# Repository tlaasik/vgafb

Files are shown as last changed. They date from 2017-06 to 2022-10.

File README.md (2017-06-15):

# VgaFB

Minimalistic VGA framebuffer hardware and software for microcontrollers (right now only tested on Arduino Uno and Nano).

## Features
* simple hardware (just 3x2:1 mux and 64KB SPI memory chip), but just enough to have low CPU utilization
* has integraion with high level u8g2 and u8x8 API. These provide monochrome font and graphics rendering
* supports 2 colors: black and a color selected by RGB jumper
* up to 640x480 resolution (64KB address space, 1bit per pixel)
* fast screen clear and fast vertical scrolling
* (optional) generates pixel clock by multiplying MCU clock by 2x 2.5x 3x 4x or 5x
* (optional) or generates pixel clock with own oscillator 20MHz 25MHz 30Mhz 40MHz 50MHz. MCU should use it

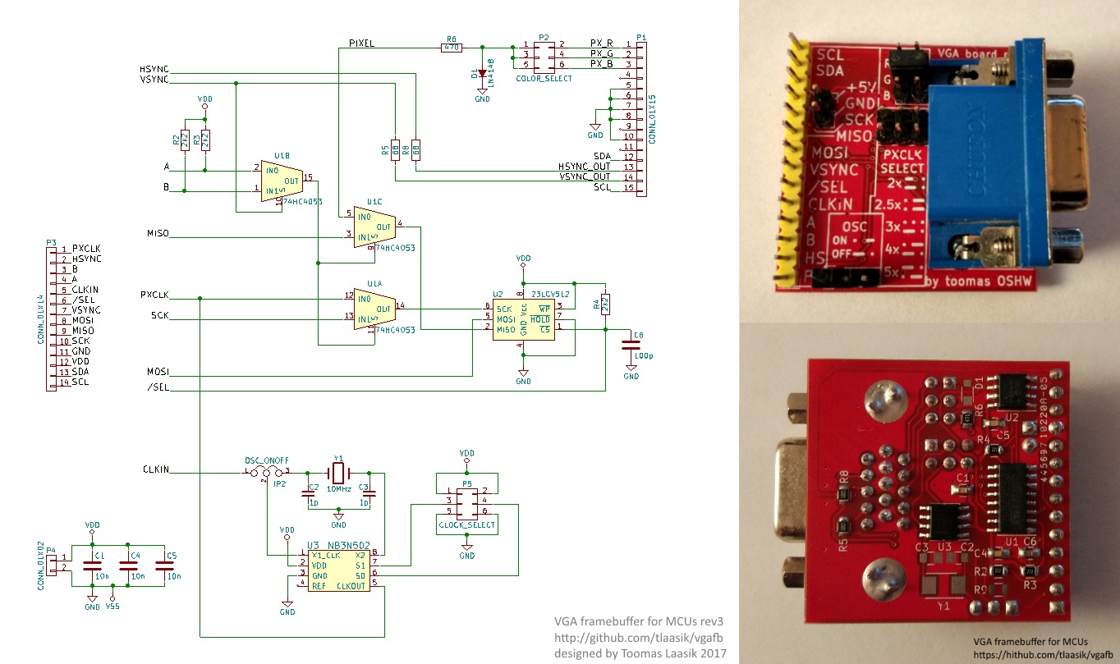
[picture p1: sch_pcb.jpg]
Schematic and pcb pictures


## Usage
1. Decide how to generate pixel clock, this may limit what resolutions are available. For example, Arduino may run at 16MHz and generate 8MHz that is fed into CLKIN. Then using 2.5x multiplier 20MHz pixel clock is generated suitable for 400x300@60Hz and 256x256@60Hz modes
2. Wire this schematic together with your Arduino board or chip
3. Download [arduino_lib/](arduino_lib/) and place the contents where your arduino libraries are (usually c:\Users\<username>3\Documents\Arduino\libraries\) or directly in your project folder
4. See [arduino_lib/examples/TextOnScreen_8x2g.ino](arduino_lib/examples/TextOnScreen_8x2g.ino)

List of modes supported (format tells screen width and height, refresh rate and required pixel clock)
* vgamode_400x300_60Hz_20MHz
* vgamode_256x256_60Hz_20MHz
* vgamode_640x480_75Hz_32MHz
* vgamode_320x240_75Hz_16MHz
* vgamode_640x400_85Hz_32MHz
* vgamode_320x200_85Hz_16MHz
* vgamode_640x480_60Hz_25MHz
* vgamode_320x240_60Hz_12_6MHz
* vgamode_160x120_60Hz_6_3MHz

Wiring to Arduino Nano
```
vgafb  ardu_nano
-------------------------------------
SCL    -       monitor I2C DDC clock, no need to connect
SDA    -       monitor I2C DDC data, no need to connect
+5V    +3..5V
GND    ground
SCK    D13     SPI clock in
MISO   D12     SPI data out
MOSI   D11     SPI data in
VSYNC  D10     vertical sync in
/SEL   D4      SPI memory chip select in
CLKIN  D3      clock in, it's multiplied to get pixel clock (right now VgaFB_Begin configures it to 8MHz)
A      D9      mode in if normal vsync, leave hi-z or drive high if inverted vsync
B      D8      mode in if inverted vsync, leave hi-z or drive high if normal vsync
HS     D5      horizontal sync in
PX     -       pixel clock out (without clock mult. chip it's pixel clock in)

/SEL, A and B pins can be assigned elsewhere on Arduino Nano. Other pins are fixed due
to hardware resources like PWM and SPI tied to specific pins.
```

## Example code
```C
#include <U8x8lib.h>
#include <SPI.h>
#include <VgaFB_u8x8.h>

U8G2_VGAFB_400X300_60Hz_20MHz_GENERIC_1_VGAFBBUS u8g2(U8G2_R0, /*mul/div=*/5, 4, /* cs=*/ 4, /* a=*/ 9);

// Generate 8MHz that will be multiplied by 2.5 (set by jumpers) to get 20MHz pixel clock.
// Since Arduino itself runs at 16MHz we told in u8g2 constructor that the multiplier is 1.25
void setupClockGen() {
	OCR2A = 0;
	TCCR2A = _BV(WGM21) | _BV(COM2B0); // toggle B on compare (pin 5, Arduino port: D3)
	TCCR2B = 1; // prescale 1
	pinMode(3, OUTPUT);
}
void setup() {
	setupClockGen();
	u8g2.begin();
}
void loop() {
	u8g2.firstPage();
	do {
		u8g2.setFont(u8g2_font_ncenB14_tr);
		u8g2.drawStr(0, 20, "VGA framebuffer for Arduino Nano");
		u8g2.drawStr(130, 260, "Running at 400x300 60Hz");
		u8g2.setFont(u8g2_font_ncenB08_tr);
		u8g2.drawStr(130, 280, "Using u8g2 for rendering text");
		u8g2.drawStr(0, 40, "https://github.com/tlaasik/vgafb");
		u8g2.drawFilledEllipse(100, 100, 90, 30);
	} while (u8g2.nextPage());
	
	_delay_ms(4000);
	VgaFB_Scroll(u8g2.getVgaFB(), 300);
	_delay_ms(800);
}
```

## Low level C API (not safe, buf fast)
```C
void VgaFB_ConfigBoard(vgafb_t * vgafb, uint8_t mul, uint8_t div, uint8_t cs_pin, uint8_t ab_pin);
bool VgaFB_Begin(vgafb_t * vgafb, vgamode_t mode);
void VgaFB_End(vgafb_t * vgafb);
void VgaFB_DisplayEnabled(vgafb_t * vgafb, bool enabled);
void VgaFB_Clear(vgafb_t * vgafb);
void VgaFB_Scroll(vgafb_t * vgafb, int16_t deltaScanline);
void VgaFB_Write(vgafb_t * vgafb, uint_vgafb_t dst, uint8_t * src, uint_vgafb_t cnt);
void VgaFB_Read(vgafb_t * vgafb, uint_vgafb_t src, uint8_t * dst, uint_vgafb_t cnt);
// uint_vgafb_t is usually uint16_t (VGAFB_VRAM_ADDR_LENGTH==2)
```

## Pictures of it working

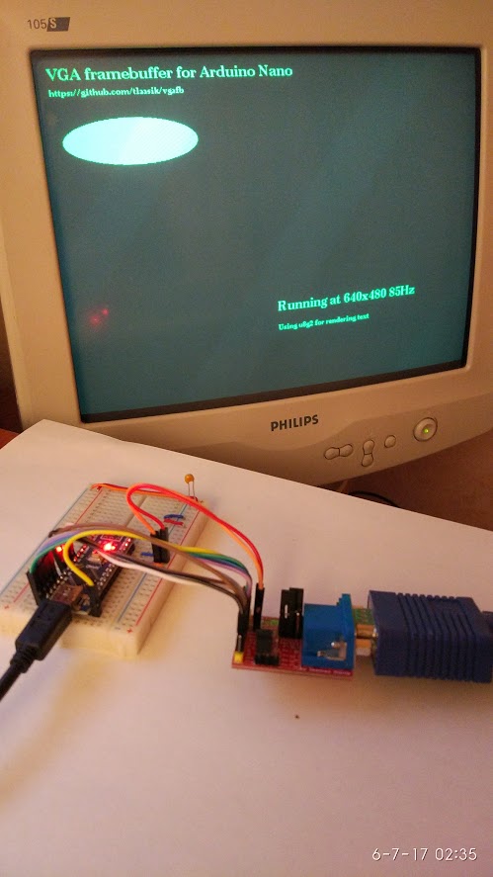
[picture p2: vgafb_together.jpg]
All together


(used an old monitor, because it supported more refresh rates on low resolution than my more modern LCD)

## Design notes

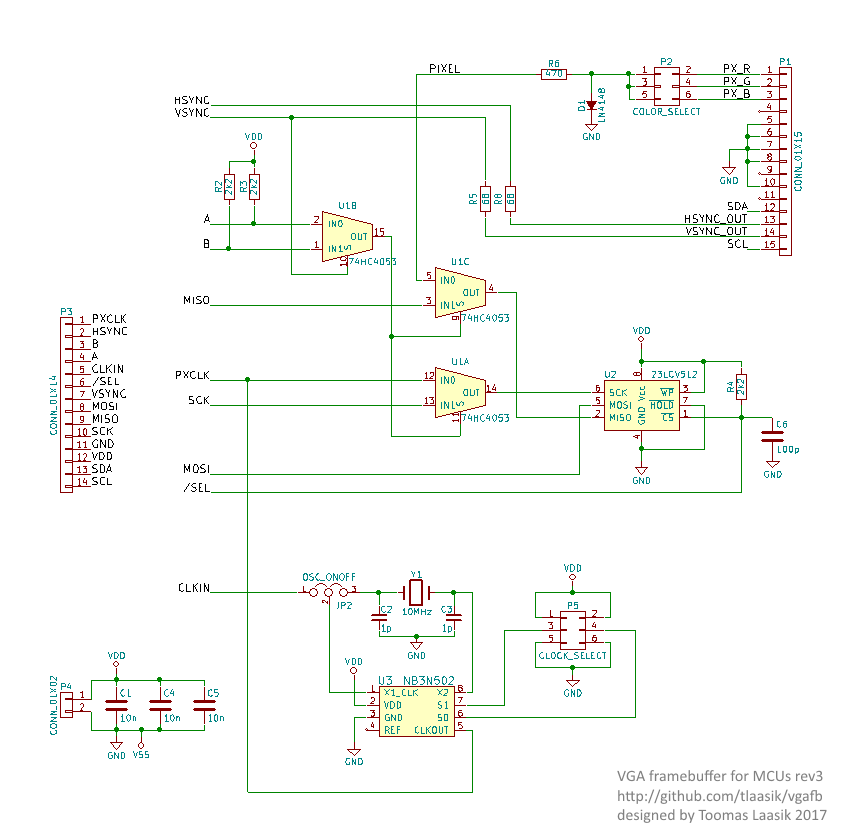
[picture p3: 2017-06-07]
vgafb_rev3_sch.png

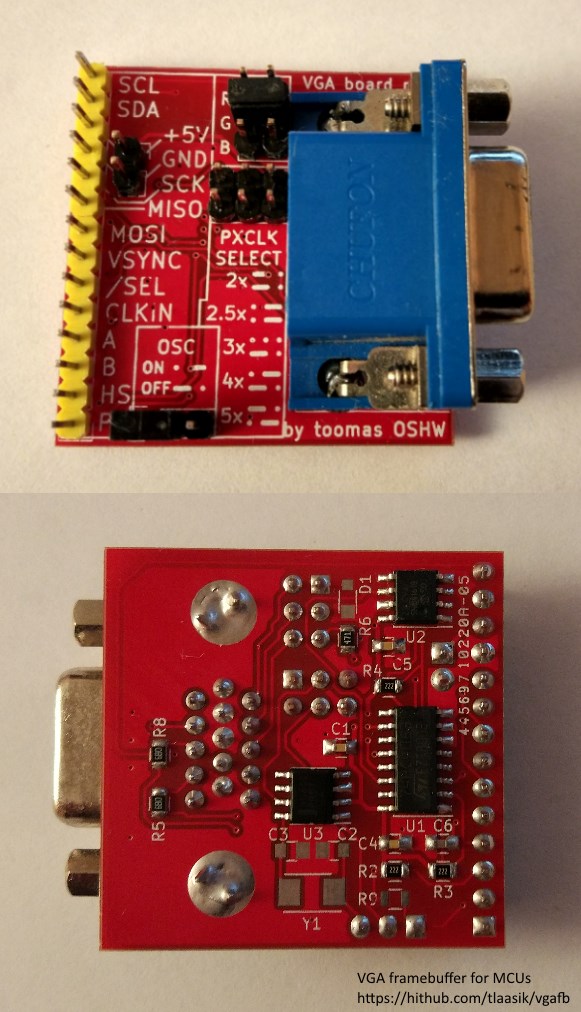
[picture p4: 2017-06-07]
2x_board.jpg

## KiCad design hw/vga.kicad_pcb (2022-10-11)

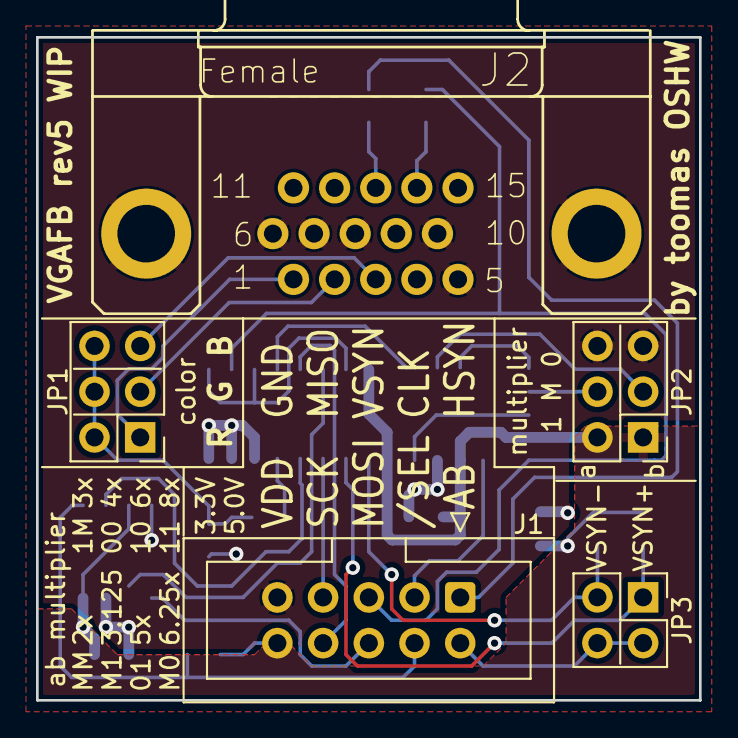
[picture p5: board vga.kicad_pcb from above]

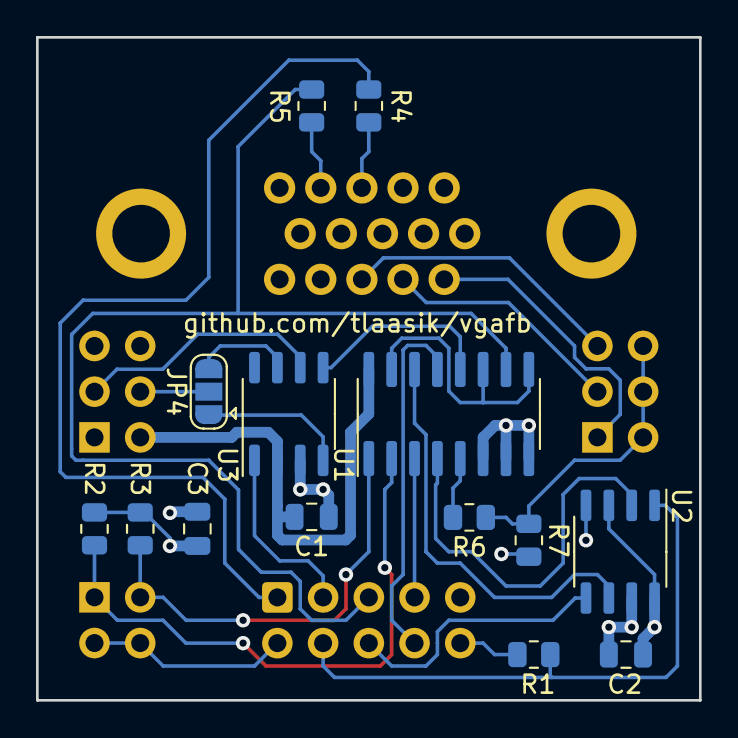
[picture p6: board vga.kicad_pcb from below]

Board: 2 copper layers, 36.8 x 36.8 mm, 19 parts (14 on the bottom side), 27 nets.

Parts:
C1, C2: 10n; C_0805_2012Metric
C3: 100n; C_0805_2012Metric
J1: Conn_02x05_Odd_Even; IDC-Header_2x05_P2.54mm_Vertical
J2: DB15_Female_HighDensity_MountingHoles; con-subd-HDF15H
JP1: color; PinHeader_2x03_P2.54mm_Vertical
JP2: multiplier; PinHeader_2x03_P2.54mm_Vertical
JP3: Conn_02x02_Odd_Even; PinHeader_2x02_P2.54mm_Vertical
JP4: SolderJumper_3_Bridged12; SolderJumper-3_P1.3mm_Open_RoundedPad1.0x1.5mm
R1, R2, R3: 10k; R_0805_2012Metric
R4, R5: 22; R_0805_2012Metric
R6: 220; R_0805_2012Metric
R7: 100; R_0805_2012Metric
U1: 74HC4053; SOIC-16_3.9x9.9mm_P1.27mm
U2: 23LCV512; SO-8_3.9x4.9mm_P1.27mm
U3: ICS501; SO-8_3.9x4.9mm_P1.27mm

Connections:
/AB: J1.2, JP3.2, JP3.4
/CLKIN: J1.3, U3.1 (X1_ICLK)
/HSYNC: J1.1, R4.2
/MISO: J1.7, U1.3 (IN1)
/MOSI: J1.6, U2.5 (SI)
/PIXEL: R6.2, U1.5 (IN0)
/PXCLK: U1.12 (IN0), U3.5 (CLK)
/PX_B: J2.3, JP1.5
/PX_G: J2.2, JP1.3
/PX_R: J2.1, JP1.1
/S0_a: JP2.3, U3.6 (S0)
/S1_b: JP2.4, JP4.2 (C)
/SCK: J1.8, U1.13 (IN1)
/VSYNC: J1.5, R5.2, U1.10 (S)
//SEL: J1.4, R1.1, U2.1 (~CS)
GND: C1.2, C2.2, C3.2, J1.9, J2.0, J2.5, J2.6, J2.7, J2.8, J2.10, JP2.5, JP2.6, R7.2, U1.6 (INH), U1.7 (VEE), U1.8 (GND), U2.4 (GND), U2.7 (~HOLD), U3.3 (GND)
unnamed: J2.13, R4.1
unnamed: J2.14, R5.1
unnamed: JP1.2, JP1.4, JP1.6, R6.1, R7.1
unnamed: JP3.1, R2.2, U1.2 (IN0)
unnamed: JP3.3, R3.2, U1.1 (IN1)
unnamed: JP4.1 (A), U3.4 (S1)
unnamed: JP4.3 (B), U3.7 (OE)
unnamed: U1.4 (OUT), U2.2 (SO)
unnamed: U1.9 (S), U1.11 (S), U1.15 (OUT)
unnamed: U1.14 (OUT), U2.6 (SCK)
VDD: C1.1, C2.1, C3.1, J1.10, JP2.1, JP2.2, R1.2, R2.1, R3.1, U1.16 (VDD), U2.3 (~WP), U2.8 (VDD), U3.2 (VDD)

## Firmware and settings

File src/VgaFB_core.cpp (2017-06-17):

/*

VgaFB_core.cpp

Minimalistic VGA framebuffer for microcontrollers
https://github.com/tlaasik/vgafb/

-------------------------------------------------------------------------------

Copyright (c) 2017, toomas.laasik@gmail.com
All rights reserved.

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
-------------------------------------------------------------------------------
*/
#include "stdint.h"
#include <SPI.h>
#include "VgaFB_core.h"
//not using TimerHelpers.h by Nick Gammon any more (http://www.gammon.com.au/forum/?id=11504)


#define SET_PORT_PIN(port, pin_mask) (*(port) |= (pin_mask))
#define CLR_PORT_PIN(port, pin_mask) (*(port) &= ~(pin_mask))
#define VGAFB_START_CRIT() uint8_t _sreg = SREG; noInterrupts()
#define VGAFB_END_CRIT() SREG = _sreg

#ifdef VGAFB_DEBUG
#define VGAFB_DEBUG_CLR(x,y) (x&=(~(1<<y)))
#define VGAFB_DEBUG_SET(x,y) (x|=(1<<y))
#else
#define VGAFB_DEBUG_CLR(x,y)
#define VGAFB_DEBUG_SET(x,y)
#endif

static vgafb_t* cur_vgafb = 0;

ISR(TIMER1_OVF_vect)
{
	if (cur_vgafb == 0 || !cur_vgafb->enabled) // not initialized or not enabled
		return;

	VGAFB_DEBUG_SET(PORTD, VGAFB_DEBUG_PIN_ISR);

	// if we're still in PXOUT mode then get out from it
	// prepare for clocking pixels out (send address)
	SPI.beginTransaction(cur_vgafb->sramSpiSettings);

	//_delay_us(11);

	// set mode to SPI and force any ongoing transfer to end by setting /CS=1
	// (most likely we already were in this state, but we need to be sure here)
	SET_PORT_PIN(cur_vgafb->cs_port, cur_vgafb->cs_pin_mask);
	SET_PORT_PIN(cur_vgafb->ab_port, cur_vgafb->ab_pin_mask);

	// start READ cmd
	CLR_PORT_PIN(cur_vgafb->cs_port, cur_vgafb->cs_pin_mask);
	VRAM_READ_START(cur_vgafb->vmemPtr);

	// set mode to PXOUT. Pixels start clocking out after vsync edge.
	// this disconnects video hw from SPI so we can end transaction
	CLR_PORT_PIN(cur_vgafb->ab_port, cur_vgafb->ab_pin_mask);

	SPI.endTransaction();

	VGAFB_DEBUG_CLR(PORTD, VGAFB_DEBUG_PIN_ISR);
}


static void VgaFB_WaitAndStart(vgafb_t* vgafb)
{
	// wait until all white pixels are clocked out
	// (those << and >> ensure that there's no uint16 overflow by sacrificing precision by 2 bits)
	uint16_t v = (((vgafb->vmemLastPixelOffset + vgafb->vSyncTimerIncCount) >> 2) * vgafb->pxclk_div / vgafb->pxclk_mul) << 2;
	while (TCNT1 < v);
	
	// take exclusive access to SPI bus
	SPI.beginTransaction(vgafb->sramSpiSettings);
}

static void VgaFB_StartTranscation(vgafb_t* vgafb)
{
	// if it's enabled we need to wait until the last white pixel has been clocked out to display
	if (vgafb->enabled)
	{
		// (need this later)
		uint16_t tcntValueBeforeWait = TCNT1;

		VgaFB_WaitAndStart(vgafb);

		// Between "while" and "SPI.beginTransaction" Timer1 overflowed (rare, but occurs).
		// This means that we're holding back Timer1 ISR that needs to run NOW
		// to start clocking out next frame. By ending SPI transaction Timer1 ISR
		// will enter immediately and we will have to wait until the last white pixel
		// have been clocked out.
		if (TCNT1 < tcntValueBeforeWait)
		{
			SPI.endTransaction();

			VgaFB_WaitAndStart(vgafb);

			// Theoretically Timer1 may have overflown once again, but we can ignore that
			// because if that's the case then:
			// * there's no VGA Front Porch or in there are white pixels. Either way
			//   this condition mustn't appear during normal operation
			// * there's some other ISR that runs too long (no ISR mustn't take longer
			//   than one scanline time that's roughly ~50us, depending on vga mode)
			// * even if overflow happened we recover from it gracefully. One frame
			//   is skipped (will draw black)
		}
	}
	else {
		SPI.beginTransaction(vgafb->sramSpiSettings);
	}

	// ! we're in time critical section now until _endSpiTransaction is called
	// (interrupts were disabled in SPI.beginTransaction)

	VGAFB_DEBUG_SET(PORTD, VGAFB_DEBUG_PIN_TRANSACTION);

	// exit PXOUT mode and deselect vram /CS=1
	// (most likely we already were in this state, but we need to be sure here)
	SET_PORT_PIN(vgafb->cs_port, vgafb->cs_pin_mask);
	SET_PORT_PIN(vgafb->ab_port, vgafb->ab_pin_mask);
	// !cpu is way too slow for this. natural delay is enough! u8x8->gpio_and_delay_cb(u8x8, U8X8_MSG_DELAY_NANO, u8x8->display_info->post_chip_enable_wait_ns, NULL);
	CLR_PORT_PIN(vgafb->cs_port, vgafb->cs_pin_mask);
}

static void VgaFB_EndTransaction(vgafb_t* vgafb)
{
	// !cpu is way too slow for this, natural delay is enough! u8x8->gpio_and_delay_cb(u8x8, U8X8_MSG_DELAY_NANO, u8x8->display_info->pre_chip_disable_wait_ns, NULL);
	SET_PORT_PIN(vgafb->cs_port, vgafb->cs_pin_mask);
	VGAFB_DEBUG_CLR(PORTD, VGAFB_DEBUG_PIN_TRANSACTION);
	SPI.endTransaction();
}


/**
* Calling this will read VRAM and adjust vgafb->vmemLastPixelOffset.
* Large vmemLastPixelOffset values will significantly slow down VRAM access writes
*/
static void VgaFB_Trim(vgafb_t* vgafb)
{
	uint8_t b[VGAFB_MAX_SPI_TRANSACTION_BYTES];

	// first read one byte back, because it's likely that it won't be zero
	uint8_t bytesToReadBack = 1;
	while (vgafb->vmemLastPixelOffset >= bytesToReadBack)
	{
		VgaFB_StartTranscation(vgafb);
		VRAM_READ_START(vgafb->vmemPtr + vgafb->vmemLastPixelOffset - bytesToReadBack);
		VRAM_TRANSFER(b, bytesToReadBack);
		VgaFB_EndTransaction(vgafb);

		while (bytesToReadBack--)
		{
			if (b[bytesToReadBack] != 0)
				return;
			vgafb->vmemLastPixelOffset--;
		}

		// tell it to read back a block, because it may be that the screen is mostly
		// black and a few white pixels on bottom screen part were white
		bytesToReadBack = VGAFB_MAX_SPI_TRANSACTION_BYTES;
	}
}

void VgaFB_ConfigBoard(vgafb_t* vgafb, uint8_t mul, uint8_t div, uint8_t cs_pin, uint8_t ab_pin)
{
	uint8_t cs_port = digitalPinToPort(cs_pin);
	uint8_t ab_port = digitalPinToPort(ab_pin);
	if (cs_port == NOT_A_PIN || ab_port == NOT_A_PIN)
		return; // XXX this is fail, but there's no way to indicate it right now

	vgafb->cs_port = portOutputRegister(cs_port);
	vgafb->ab_port = portOutputRegister(ab_port);
	vgafb->cs_pin_mask = digitalPinToBitMask(cs_pin);
	vgafb->ab_pin_mask = digitalPinToBitMask(ab_pin);

	pinMode(VGAFB_FIXED_PIN_HSYNC, OUTPUT);
	pinMode(VGAFB_FIXED_PIN_VSYNC, OUTPUT);
	pinMode(ab_pin, OUTPUT);
	pinMode(cs_pin, OUTPUT);

	vgafb->pxclk_mul = mul;
	vgafb->pxclk_div = div;

#ifdef VGAFB_DEBUG
	pinMode(VGAFB_DEBUG_PIN_TRANSACTION, OUTPUT);
	pinMode(VGAFB_DEBUG_PIN_ISR, OUTPUT);
#endif
}
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

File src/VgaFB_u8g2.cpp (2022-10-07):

/*

VgaFB_u8g2.cpp

U8x8 and U8g2 library integration for VgaFB (Minimalistic VGA framebuffer for microcontrollers)
https://github.com/tlaasik/vgafb/

-------------------------------------------------------------------------------

Copyright (c) 2017, toomas.laasik@gmail.com
All rights reserved.

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
-------------------------------------------------------------------------------
*/
#include <stdint.h>
#include <U8x8lib.h>
#include <U8g2lib.h>
#include "VgaFB_core.h"
#include "VgaFB_u8g2.h"


// hide vgafb 16bit pointer into i2c_address and i2c_started.
// u8x8_t should really have void* that can point to additional state object like vgafb_t
#define VGAFB_HIDE_POINTER(u8x8, vgafb) *((uint16_t *)&(u8x8)->i2c_address) = (uint16_t)(vgafb)
#define VGAFB_UNHIDE_POINTER(u8x8) (vgafb_t *)(*((uint16_t *)&(u8x8)->i2c_address))


// -------------------------------- C part --------------------------------

static uint8_t u8x8_d_vgafb_generic(u8x8_t *u8x8, uint8_t msg, uint8_t arg_int, void *arg_ptr)
{
	uint8_t *tilePtr;
	uint16_t basePixelOffs, pixelOffs, c3;
	uint8_t repeat, r, c, j, x, y, xx, d, t, s;

	vgafb_t* vgafb = VGAFB_UNHIDE_POINTER(u8x8);

	switch (msg)
	{
		/* copied text. delete once taken into account!
		"tile_ptr" is the address of a memory area, which contains
		one or more tiles. "cnt" will contain the exact number of
		tiles in the memory areay. The size of the memory area is 8*cnt;
		Multiple tiles in the memory area form a horizontal sequence, this
		means the first tile is drawn at x_pos/y_pos, the second tile is drawn
		at x_pos+1/y_pos, third at x_pos+2/y_pos.
		"arg_int" tells how often the tile sequence should be repeated:
		For example if "cnt" is two and tile_ptr points to tiles A and B,
		then for arg_int = 3, the following tile sequence will be drawn:
		ABABAB. Totally, cnt*arg_int tiles will be drawn. */
	case U8X8_MSG_DISPLAY_DRAW_TILE:

		x = ((u8x8_tile_t *)arg_ptr)->x_pos;
		y = ((u8x8_tile_t *)arg_ptr)->y_pos;
		if (y >= u8x8->display_info->tile_height)
			break;

		basePixelOffs = vgafb->vmemFirstPixelOffset + (((uint16_t)y) << 3) * vgafb->vmemScaledStride + u8x8->x_offset;

		for (repeat = 0; repeat < arg_int; ++repeat) // repeat as many times requested
		{
			tilePtr = ((u8x8_tile_t *)arg_ptr)->tile_ptr;
			for (r = 0; r < 8; ++r) // iterate over tile rows. we know its size is constant 8
			{
				t = ((u8x8_tile_t *)arg_ptr)->cnt;
				for (c = 0; c < t; ++c) // iterate over tile columns
				{
					xx = x + c + repeat * t;
					if (xx >= u8x8->display_info->tile_width)
						break;

					pixelOffs = basePixelOffs + (uint16_t)r * vgafb->vmemScaledStride + xx;

					// http://stackoverflow.com/questions/35544172/rotate-a-bitmap-represented-by-an-array-of-bytes
					// get first row pixels (i is row number) for anti-clockwise rotated tile
					d = 0;
					c3 = c << 3;
					for (j = 0; j < 8; ++j) {
						d <<= 1;
						d |= (tilePtr[j + c3] >> r) & 1;
					}

					s = vgafb->mode.scanlineHeight;
					while (s--) {
						VgaFB_Write(vgafb, pixelOffs, &d, 1);
						pixelOffs += vgafb->vmemStride;
					}
				}
			}
		}
		break;
	case U8X8_MSG_DISPLAY_SET_POWER_SAVE:
		VgaFB_DisplayEnabled(vgafb, arg_int == 0);
		break;
	default:
		return 0;
	}
	return 1;
}

/* timing from VGAFB */
static const u8x8_display_info_t u8x8_vgafb_640x480_75Hz_32MHz_display_info =
{
	/* chip_enable_level = */ 0,
	/* chip_disable_level = */ 1,

	/* post_chip_enable_wait_ns = */ 25,/* ok */
	/* pre_chip_disable_wait_ns = */ 50,/* didn't quite understand from 23LCV512 datasheet if it should be 25 or 50 */
	/* reset_pulse_width_ms = */ 1, 	/* don't care, not used */
	/* post_reset_wait_ms = */ 1,       /* don't care, not used */
	/* sda_setup_time_ns = */ 25,		/* half of 20MHz clock cycle (50ns/2) */
	/* sck_pulse_width_ns = */ 25,	    /* half of 20MHz clock cycle (50ns/2) */
	/* sck_clock_hz = */ 20000000UL,	/* ignored */
	/* spi_mode = */ 0,		            /* active high, rising edge */
	/* i2c_bus_clock_100kHz = */ 1,     /* don't care. not used */
	/* data_setup_time_ns = */ 10,      /* ok */
	/* write_pulse_width_ns = */ 50,	/* didn't quite understand from 23LCV512 datasheet, but it's 50 or less */
	/* tile_width = */ 80, // 40
	/* tile_hight = */ 60, // 25
	/* default_x_offset = */ 0,			/* there's no reason to change it */
	/* flipmode_x_offset = */ 0,		/* no flipping, do don't care */
	/* pixel_width = */ 640,
	/* pixel_height = */ 480
};
static const u8x8_display_info_t u8x8_vgafb_400x300_60Hz_20MHz_display_info =
{
	/* chip_enable_level = */ 0,
	/* chip_disable_level = */ 1,

	/* post_chip_enable_wait_ns = */ 25,/* ok */
	/* pre_chip_disable_wait_ns = */ 50,/* didn't quite understand from 23LCV512 datasheet if it should be 25 or 50 */
	/* reset_pulse_width_ms = */ 1, 	/* don't care, not used */
	/* post_reset_wait_ms = */ 1,       /* don't care, not used */
	/* sda_setup_time_ns = */ 25,		/* half of 20MHz clock cycle (50ns/2) */
	/* sck_pulse_width_ns = */ 25,	    /* half of 20MHz clock cycle (50ns/2) */
	/* sck_clock_hz = */ 20000000UL,	/* should use 16MHz here? */
	/* spi_mode = */ 0,		            /* active high, rising edge */
	/* i2c_bus_clock_100kHz = */ 1,     /* don't care. not used */
	/* data_setup_time_ns = */ 10,      /* ok */
	/* write_pulse_width_ns = */ 50,	/* didn't quite understand from 23LCV512 datasheet, but it's 50 or less */
	/* tile_width = */ 50,
	/* tile_hight = */ 37,
	/* default_x_offset = */ 0,			/* there's no reason to change it */
	/* flipmode_x_offset = */ 0,		/* no flipping, do don't care */
	/* pixel_width = */ 400,
	/* pixel_height = */ 296			/* display is 300, but it's not dividable by 8, therefore using a bit lower height */
};
static const u8x8_display_info_t u8x8_vgafb_240x240_60Hz_20MHz_display_info =
{
	/* chip_enable_level = */ 0,
	/* chip_disable_level = */ 1,

	/* post_chip_enable_wait_ns = */ 25,/* ok */
	/* pre_chip_disable_wait_ns = */ 50,/* didn't quite understand from 23LCV512 datasheet if it should be 25 or 50 */
	/* reset_pulse_width_ms = */ 1, 	/* don't care, not used */
	/* post_reset_wait_ms = */ 1,       /* don't care, not used */
	/* sda_setup_time_ns = */ 25,		/* half of 20MHz clock cycle (50ns/2) */
	/* sck_pulse_width_ns = */ 25,	    /* half of 20MHz clock cycle (50ns/2) */
	/* sck_clock_hz = */ 20000000UL,	/* should use 16MHz here? */
	/* spi_mode = */ 0,		            /* active high, rising edge */
	/* i2c_bus_clock_100kHz = */ 1,     /* don't care. not used */
	/* data_setup_time_ns = */ 10,      /* ok */
	/* write_pulse_width_ns = */ 50,	/* didn't quite understand from 23LCV512 datasheet, but it's 50 or less */
	/* tile_width = */ 32,
	/* tile_hight = */ 32,
	/* default_x_offset = */ 0,			/* there's no reason to change it */
	/* flipmode_x_offset = */ 0,		/* no flipping, do don't care */
	/* pixel_width = */ 240,
	/* pixel_height = */ 240
};
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

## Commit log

2017-06-06 Added rev3 hardware schematic and board
    [vga.kicad_pcb, vga.sch]
2017-06-06 First Arduino library code commit
2017-06-13 Fixed pixel height for doublescan modes
    [VgaFB_u8x8.cpp]
2017-06-13 Removed TimerHelpers.h dependency
2017-06-15 Chagned Arduino code license to LGPL
2017-06-16 Added power save mode to VgaFB U8x8 and U8g2
2022-09-08 Upgraded project to Kicad 6
    [vga.kicad_pcb, vga.kicad_sch, vga.sch]
2022-09-26 Changed PLL chip to ICS501 and removed onboard oscillator option. Changed J1 footprint to 14 pin double row pin header. Swapped J1 pins 2 and 3 (hsync and B). J1 pin 1 is now ground (used to be pixel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
    [vga.kicad_pcb, vga.kicad_sch]
2022-09-30 Reduced J1 to 10pins by removing all non-essential pins. Reviewed comments on the schematic. Added solder jumper so that more PLL chips could be used. Changed AB input to use pullups like rev3 did (b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
    [vga.kicad_pcb, vga.kicad_sch]
2022-10-06 Finalized rev4 board. Added post PCB manufacturing TODOs to schematic.
    [vga.kicad_pcb, vga.kicad_sch]
2022-10-07 Updated folder structure
    [vga.kicad_sch]
2022-10-11 Cleaned up the schematic and changed some resistor values for better impedance matching
    [vga.kicad_pcb, vga.kicad_sch]
